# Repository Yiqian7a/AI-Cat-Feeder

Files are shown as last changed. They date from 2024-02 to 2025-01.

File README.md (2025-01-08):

## 设计思路

### 1.1 初代设计 v1.0

在最初的v1.0设计中，我给喂猫机设计了一个雪人外形，分离储粮仓和出粮装置，使用太阳能贴条[^1]和风力供电[^2]。

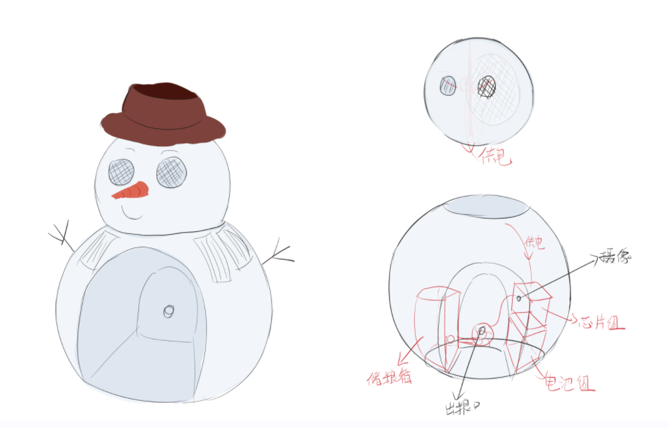
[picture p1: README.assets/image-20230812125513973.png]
图1.1
雪人身体的空腔部分（左图阴影）用来放置猫粮食盆，内部中空部分用来放置其他零部件，位置示意图如右图： 

（图1.1.1）

[^1]: （左图）雪人身体部分外侧的条状阴影。
[^2]: （右图）雪人头部内可以放入风力发电机和叶片，在雪人头部的后侧有一个大进风网口，前面的两个眼睛为出风网口。

出粮装置设计如下图，其分为两个部分：

- 蓝色的旋转件，工作时顺时针旋转，将猫粮从进粮口（右图左下的外壳缺口）带到最高点，再由重力作用将猫粮从出粮口（图1.1.1右图下部）导出。旋转件的内环有传动齿轮，这里由于前期模型丢失留到最后再介绍；
- 灰色的固定外壳，用以固定旋转件。

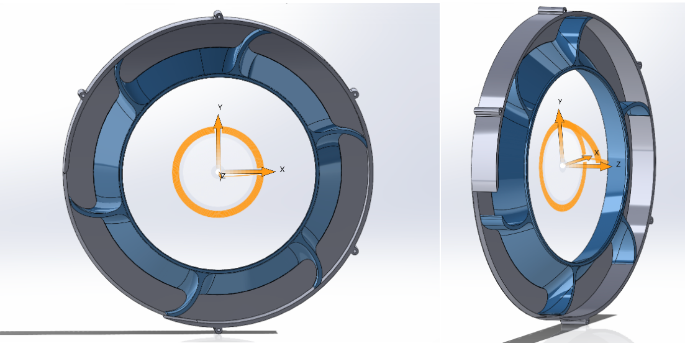
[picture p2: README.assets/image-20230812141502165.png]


（图1.1.2）

### 1.2 设计改良 v1.1

在完成设计v1.0 后的一段时间内，考虑到风力发电装置效率、组装接线、防水等问题，于是将雪人的头壳去除，改成了雪屋，并修改了3D设计：

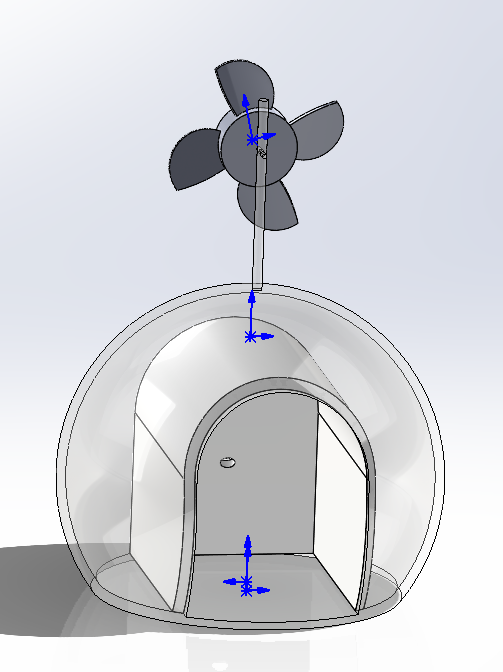
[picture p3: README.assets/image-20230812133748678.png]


（图1.2.1）

### 1.3 储粮优化 v1.2

考虑到v1.1储粮部分模型建模困难、连接组件过于复杂、更换粮食不方便等问题，我重新设计了一体式储粮送粮装置：

- 最上为进粮口，可以加上盖子；
- 主仓内有三个空腔（右图），最大的为储粮仓，左下为电机、电池仓，右下空仓没有使用；
- （左图）主仓右下角缺口凹槽为电池或用于主仓定位预留；
- （左图）控制主板和摄像头位于旋转件中间的空位（未画出），通过开孔与电池电机连接；

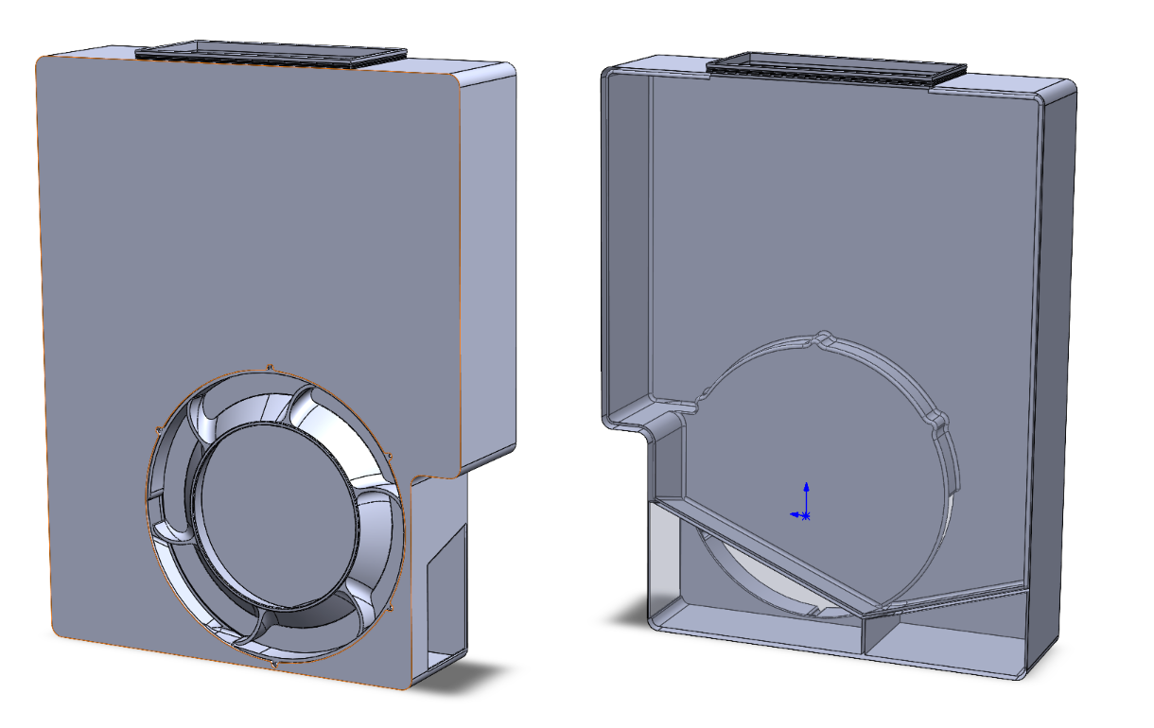
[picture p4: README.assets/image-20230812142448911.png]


（图1.3.1）

### 1.3 重制模型 v2.0

v1的设计提出不久就因为球状外壳装配繁琐、装置容错率低等问题而被否决了；同时测试v1.2版本的储粮仓由于坡度不够等问题无法顺利出粮。于是我开发了v2.0版本：

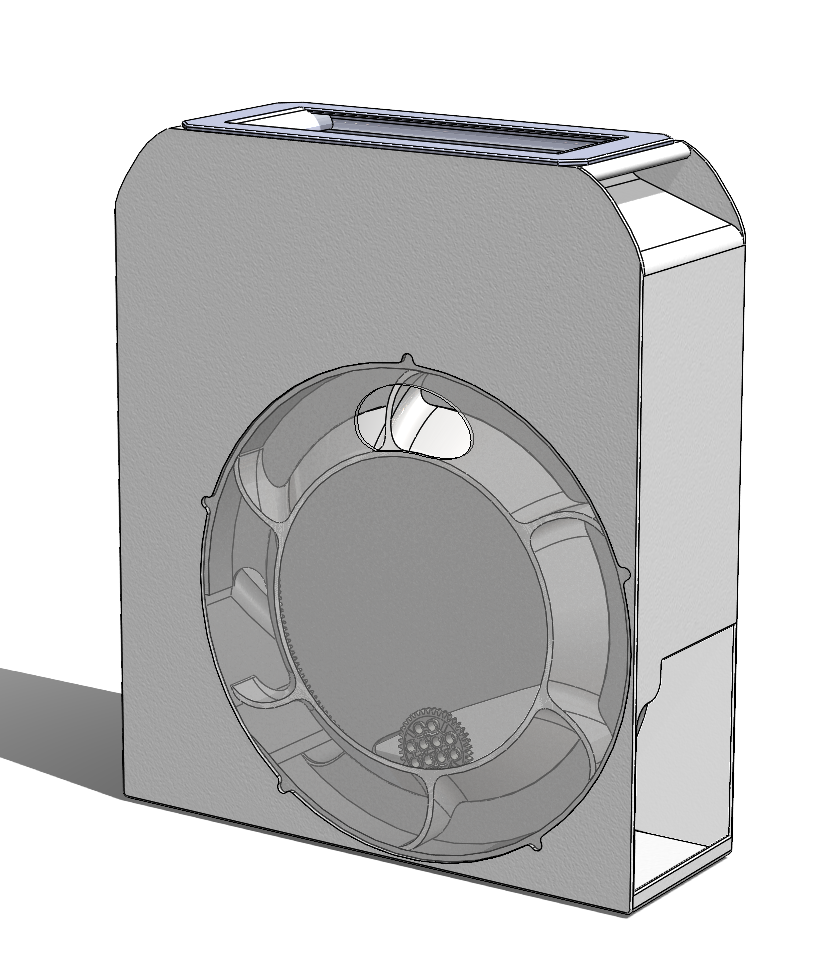
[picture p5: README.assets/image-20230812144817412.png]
（图1.3.1）

比起之前的v1.2（右），v2.0（左）版本对内部空间分配作了优化，同时增加了旋转环的尺寸和粮仓底部的倾角：

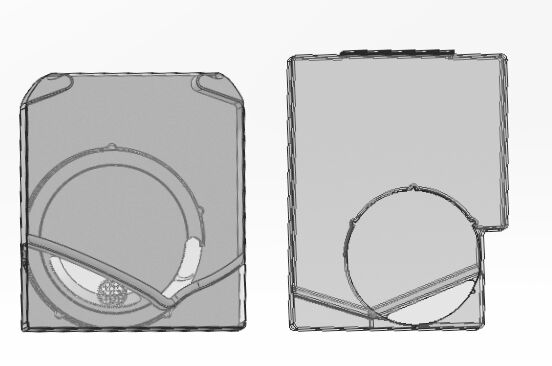
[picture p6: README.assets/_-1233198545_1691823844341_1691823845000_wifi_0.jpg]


（图1.3.2）

以下是详细讲解，左图为后视图，右图为爆炸视图：

- 最上方蓝色部分为储粮仓盖，用以防水防潮，其下方左右各有一片突出的薄片，用以卡住盖子，上方有打开盖子用的扣板；
- 在主仓上方的左右两侧有两个凹槽，是主仓的提手；

- 主仓内部分为上下两部分，上半部分用以储存猫粮，下半部分用于存放电池等各种装置；
- 最前面是一个透明挡板，同时用以展示和保护内部摄像头、主板等装置；
- 左图下部可以看到齿轮的传动连接，电机驱动该齿轮以带动出粮。

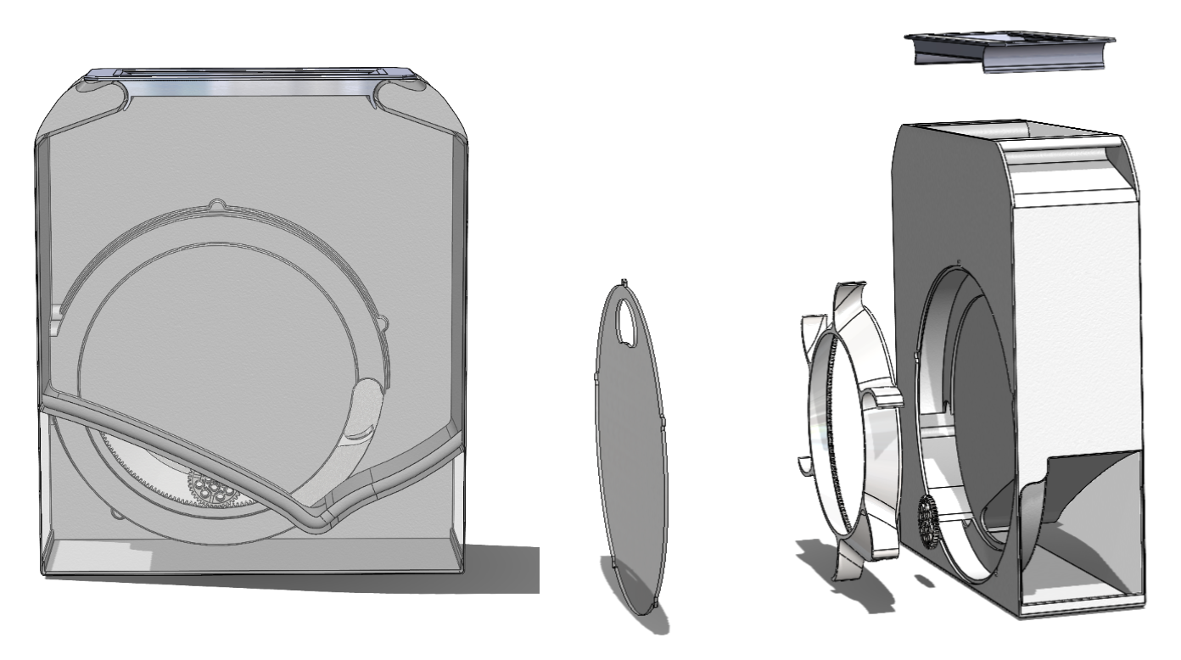
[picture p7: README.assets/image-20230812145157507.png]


（图1.3.2）

### 1.4 外壳整体 v2.1

整体外形设计为古罗马神殿风格，采用底座、外壳、屋顶三层拼装，方便拆装。主视图如下：

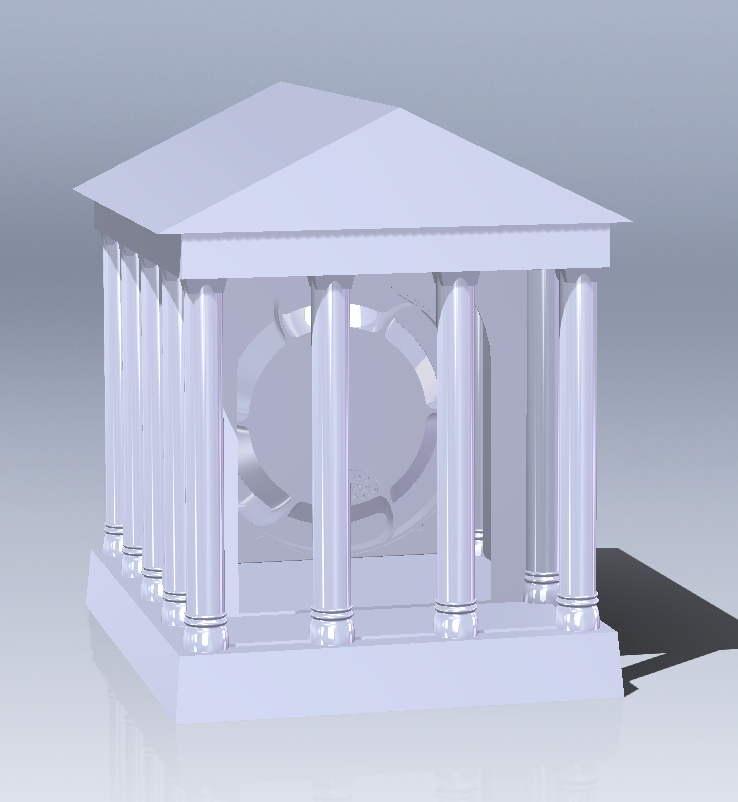
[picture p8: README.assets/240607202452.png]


顶部透视图：

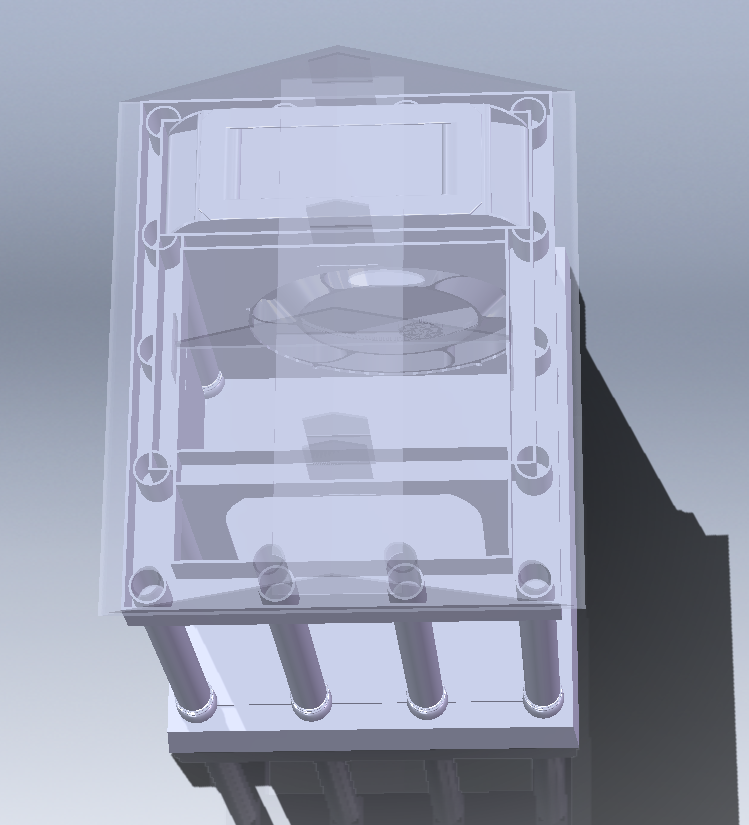
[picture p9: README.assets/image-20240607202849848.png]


### 1.5 最终版 v2.2

最终版修改了正门前的两个柱子，防止猫咪卡住或进不去，同时增大了喂猫机的内部空间。

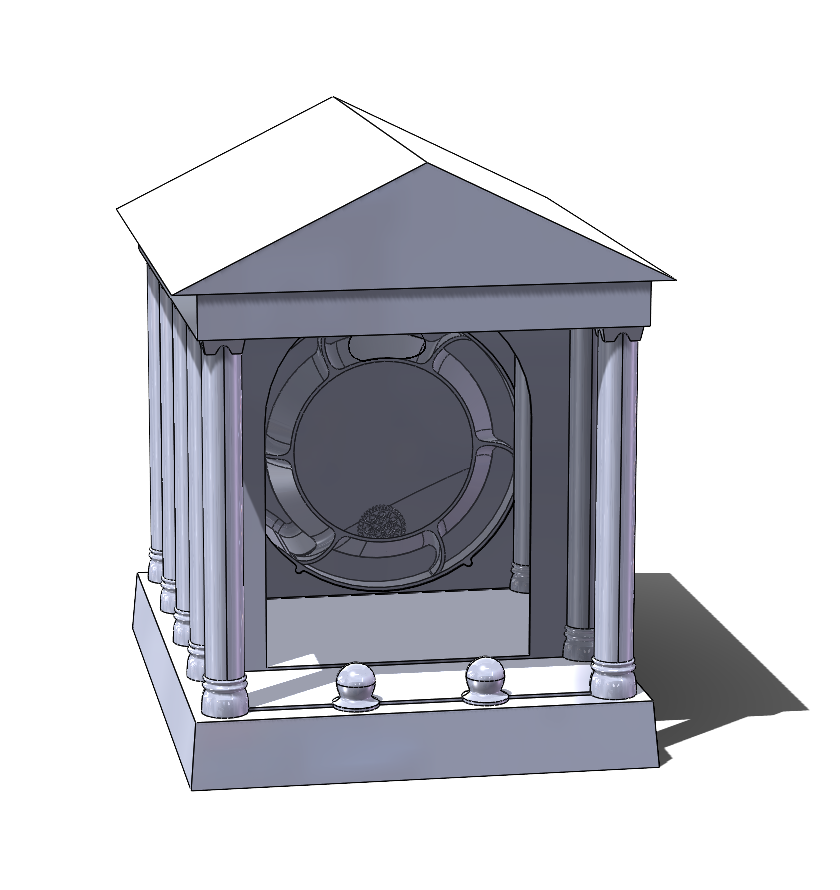
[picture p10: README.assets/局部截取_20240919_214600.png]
局部截取_20240919_214600


## 成品展示

最终结果请参照下面实物图：

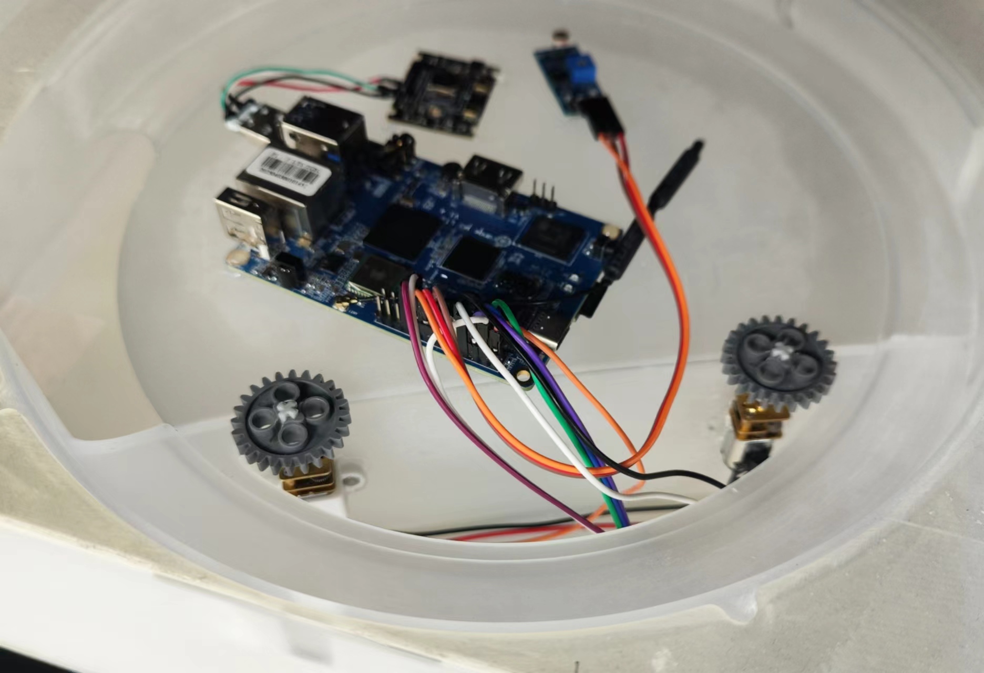
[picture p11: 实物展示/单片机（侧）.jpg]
单片机（侧）


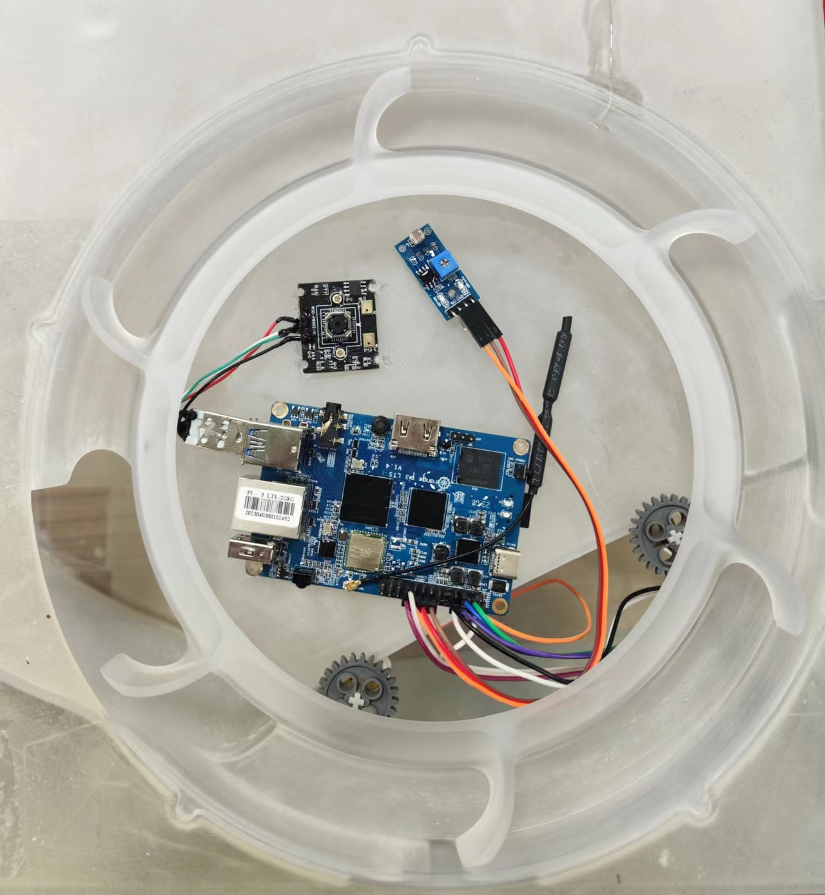
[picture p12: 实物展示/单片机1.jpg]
单片机1


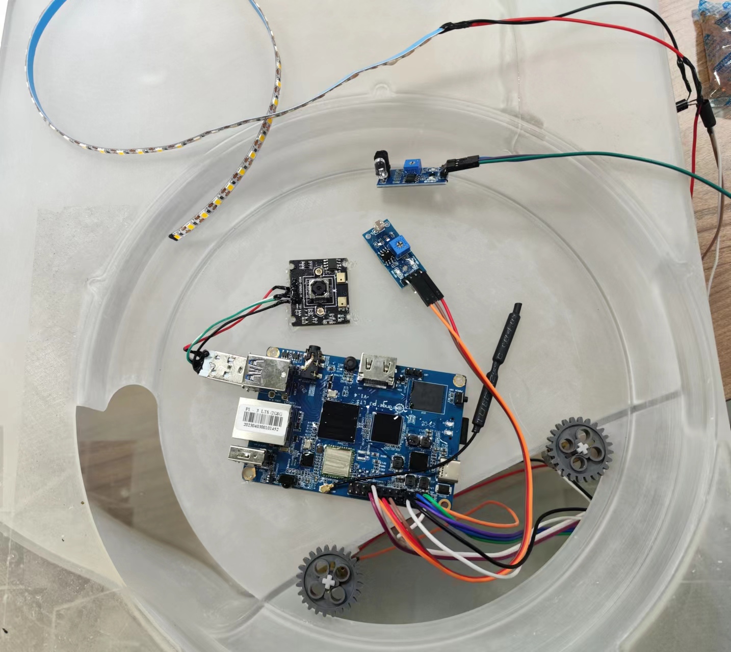
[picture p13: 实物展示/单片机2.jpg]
单片机2


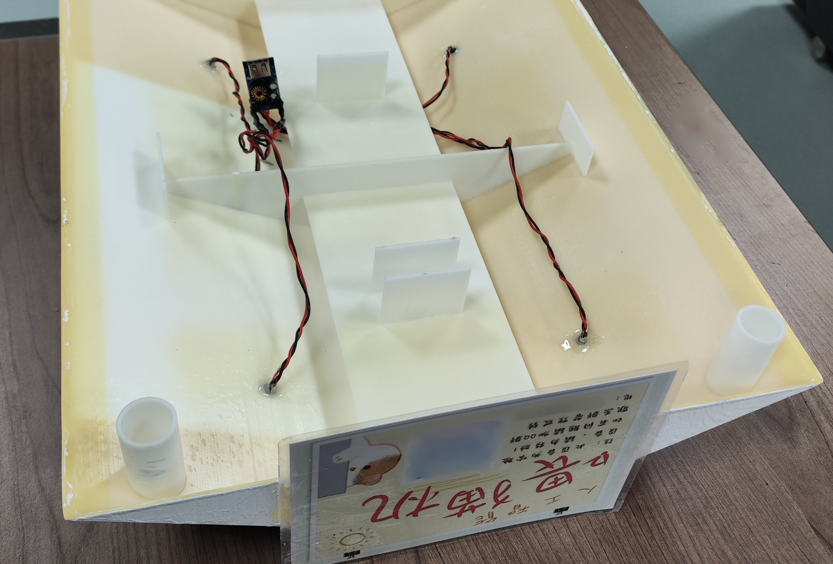
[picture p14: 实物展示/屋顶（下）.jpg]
屋顶（下）


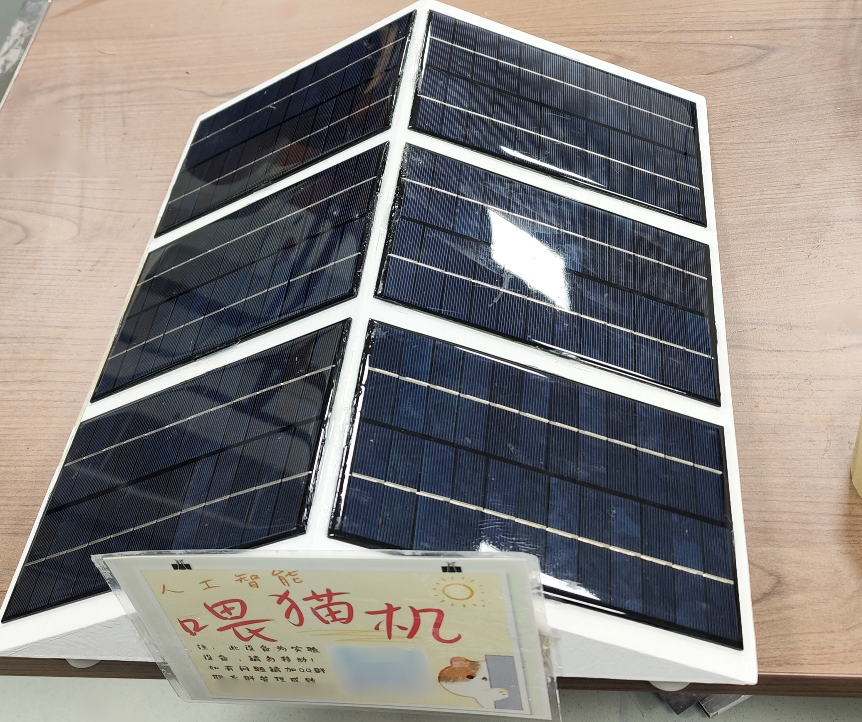
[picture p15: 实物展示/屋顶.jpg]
屋顶


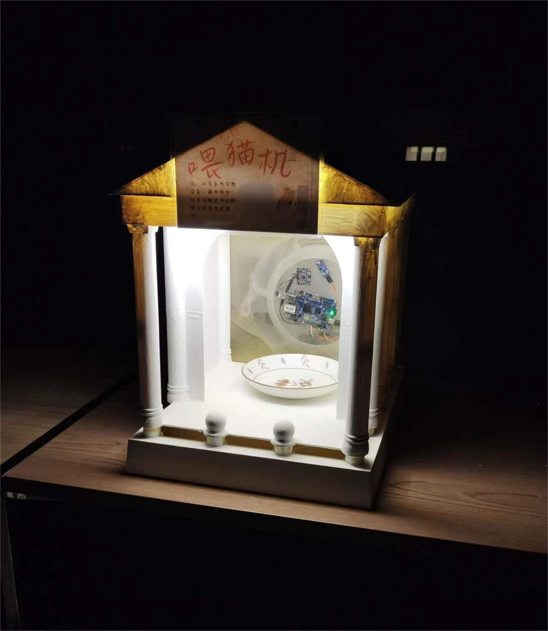
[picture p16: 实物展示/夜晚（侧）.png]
夜晚（侧）


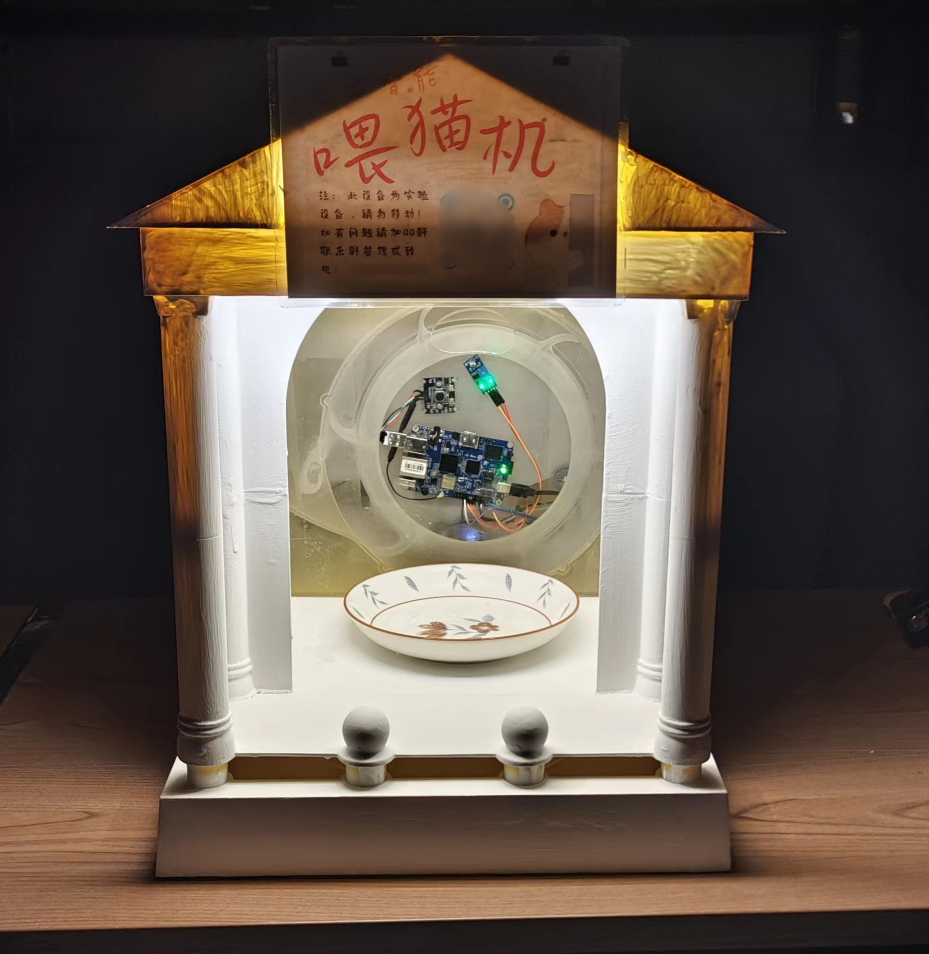
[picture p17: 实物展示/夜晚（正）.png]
夜晚（正）


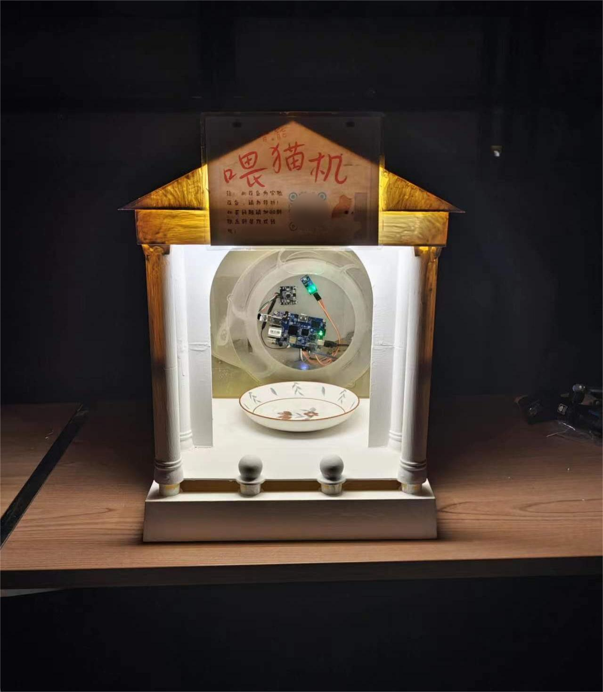
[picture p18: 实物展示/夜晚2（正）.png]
夜晚2（正）


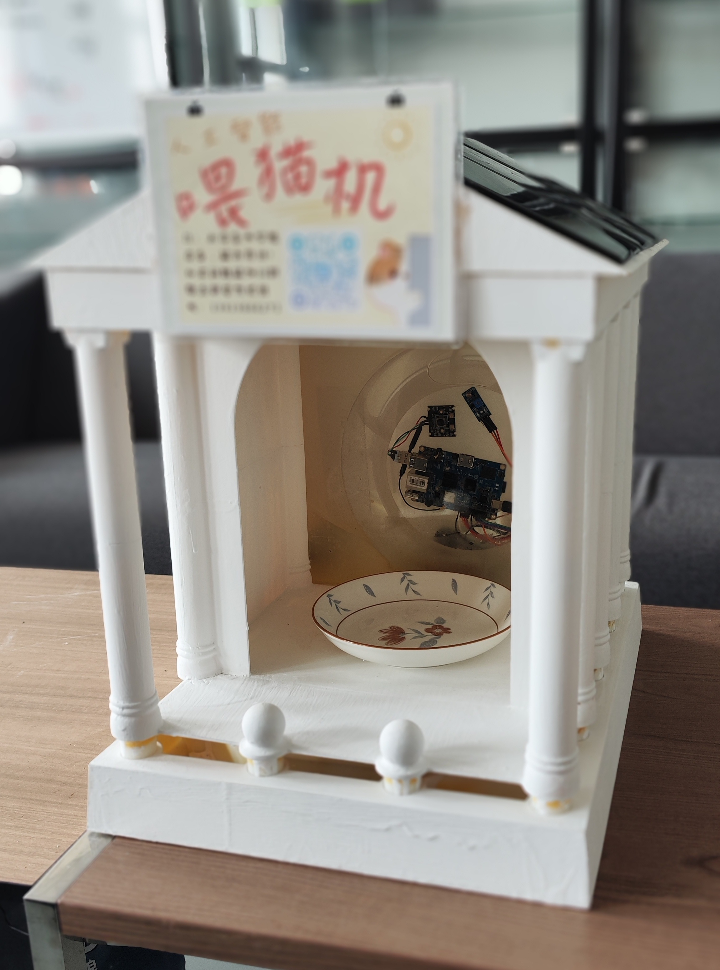
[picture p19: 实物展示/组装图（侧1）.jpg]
组装图（侧1）


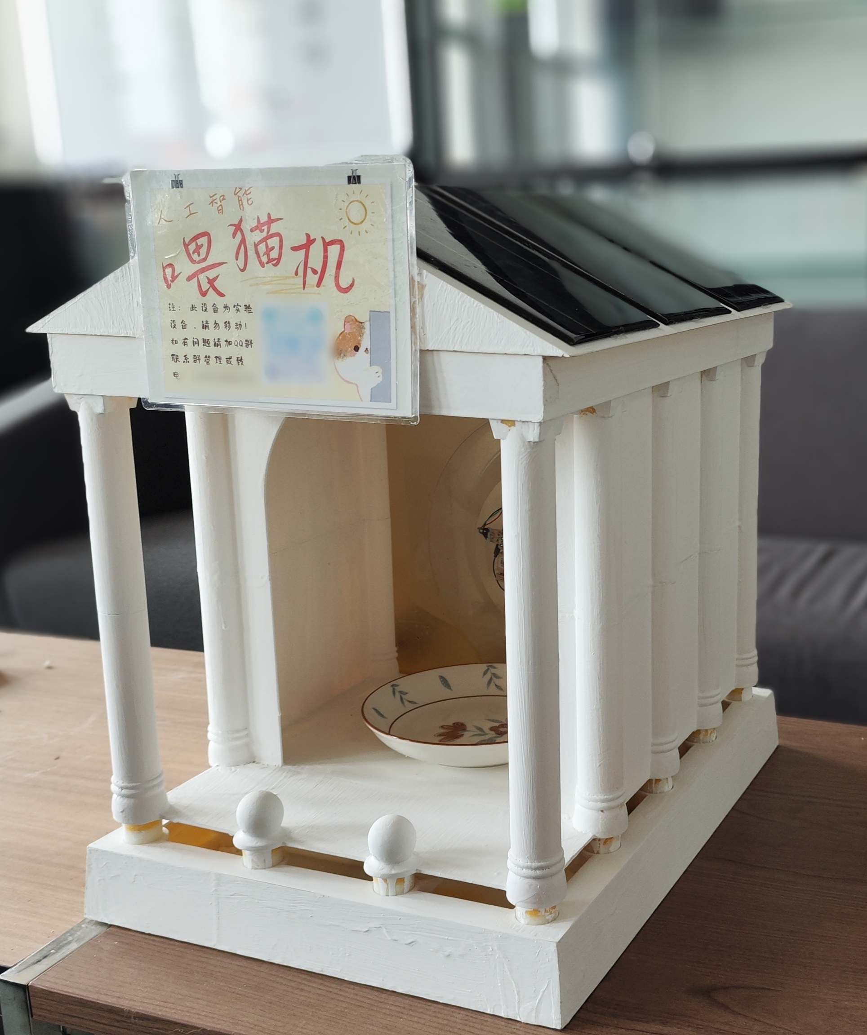
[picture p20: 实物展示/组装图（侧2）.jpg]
组装图（侧2）


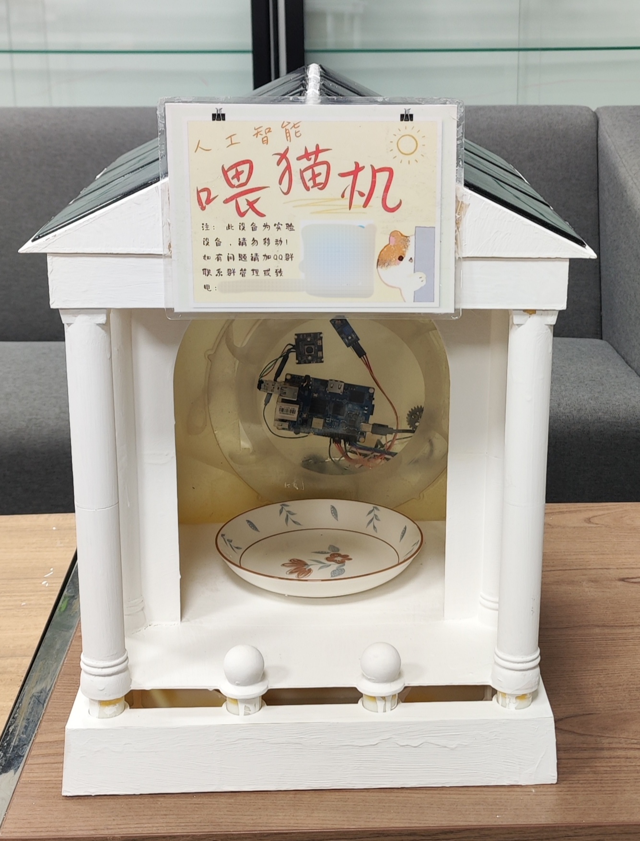
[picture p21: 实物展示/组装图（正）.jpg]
组装图（正）


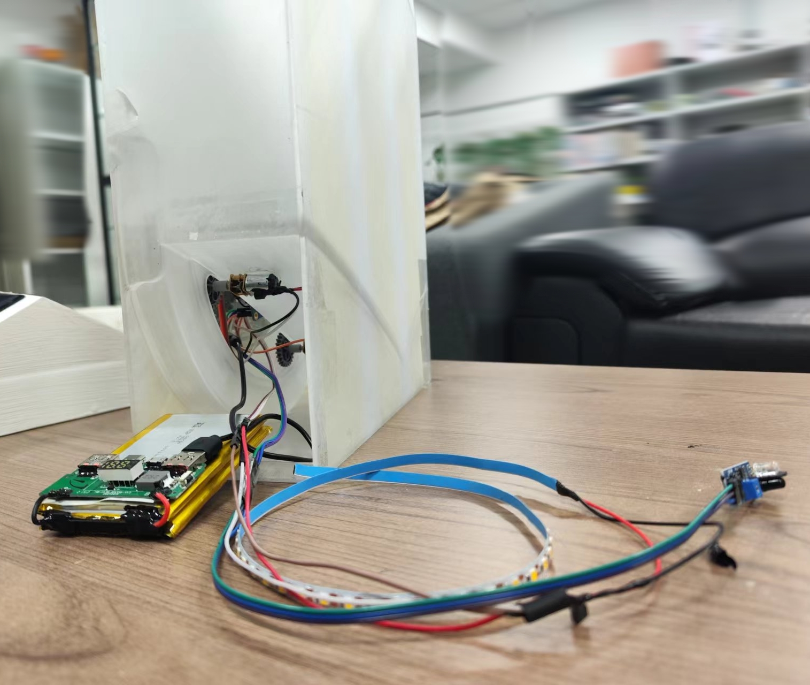
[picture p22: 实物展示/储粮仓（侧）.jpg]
储粮仓（侧）


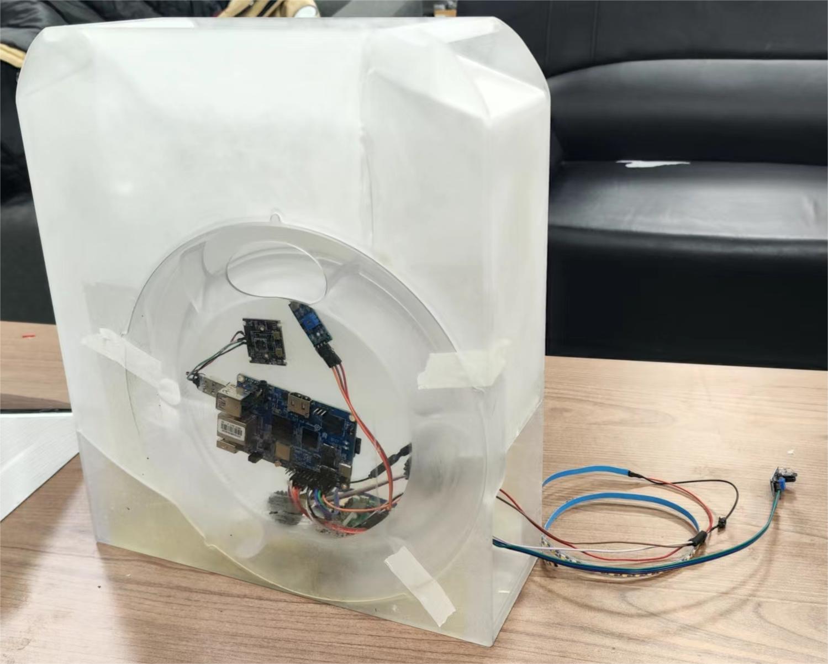
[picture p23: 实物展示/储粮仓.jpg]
储粮仓


实际使用中，转轮的设计还是容易出现卡粮的情况，因此这是一个十分大胆的设计。

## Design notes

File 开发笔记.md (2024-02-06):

## 2. 配置环境

### 2.1 安装miniconda

### 2.2 修改gpio映射

进入OPi库的路径修改

```bash
cd /usr/local/lib/
find . -name "OPi*"
```

进入OPi文件夹下，找到`pin_mappings.py`文件

将下面的映射字典替换原有的字典，注意只要修改`BOARD{ }`中的内容：

```python
_pin_map = {
    BOARD: {
        3: 122,
        5: 121,
        7: 118,
        8: 354,
        10: 355,
        11: 120,
        12: 114,
        13: 119,
        15: 362,
        16: 111,
        18: 112,
        19: 229,
        21: 230,
        22: 117,
        23: 228,
        24: 227,
        26: 360
    },
```

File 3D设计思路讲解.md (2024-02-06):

## 3D设计思路讲解

### 1. 设计思路

#### 1.1 初代设计 v1.0

在最初的v1.0设计中，我给喂猫机设计了一个雪人外形，分离储粮仓和出粮装置，使用太阳能贴条[^1]和风力供电[^2]。

雪人身体的空腔部分（左图阴影）用来放置猫粮食盆，内部中空部分用来放置其他零部件，位置示意图如右图：图1.1 

（图1.1.1）

[^1]: （左图）雪人身体部分外侧的条状阴影。
[^2]: （右图）雪人头部内可以放入风力发电机和叶片，在雪人头部的后侧有一个大进风网口，前面的两个眼睛为出风网口。

出粮装置设计如下图，其分为两个部分：

- 蓝色的旋转件，工作时顺时针旋转，将猫粮从进粮口（右图左下的外壳缺口）带到最高点，再由重力作用将猫粮从出粮口（图1.1.1右图下部）导出。旋转件的内环有传动齿轮，这里由于前期模型丢失留到最后再介绍；
- 灰色的固定外壳，用以固定旋转件。



（图1.1.2）

#### 1.2 设计改良 v1.1

在完成设计v1.0 后的一段时间内，考虑到风力发电装置效率、组装接线、防水等问题，于是将雪人的头壳去除，改成了雪屋，并修改了3D设计：



（图1.2.1）

#### 1.3 储粮优化 v1.2

考虑到v1.1储粮部分模型建模困难、连接组件过于复杂、更换粮食不方便等问题，我重新设计了一体式储粮送粮装置：

- 最上为进粮口，可以加上盖子；
- 主仓内有三个空腔（右图），最大的为储粮仓，左下为电机、电池仓，右下空仓没有使用；
- （左图）主仓右下角缺口凹槽为电池或用于主仓定位预留；
- （左图）控制主板和摄像头位于旋转件中间的空位（未画出），通过开孔与电池电机连接；



（图1.3.1）

#### 1.3 重制模型 v2.0

v1的设计提出不久就因为球状外壳装配繁琐、装置容错率低等问题而被否决了；同时测试v1.2版本的储粮仓由于坡度不够等问题无法顺利出粮。于是我开发了v2.0版本：

（图1.3.1）

比起之前的v1.2（右），v2.0（左）版本对内部空间分配作了优化，同时增加了旋转环的尺寸和粮仓底部的倾角：



（图1.3.2）

以下是详细讲解，左图为后视图，右图为爆炸视图：

- 最上方蓝色部分为储粮仓盖，用以防水防潮，其下方左右各有一片突出的薄片，用以卡住盖子，上方有打开盖子用的扣板；
- 在主仓上方的左右两侧有两个凹槽，是主仓的提手；

- 主仓内部分为上下两部分，上半部分用以储存猫粮，下半部分用于存放电池等各种装置；
- 最前面是一个透明挡板，同时用以展示和保护内部摄像头、主板等装置；
- 左图下部可以看到齿轮的传动连接，电机驱动该齿轮以带动出粮。



（图1.3.2）

#### 1.4 外壳整体 v2.1

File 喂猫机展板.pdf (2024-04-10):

# 人 工 智 能 自 动 喂 猫 机

刘宇昊、陈峻松、梁羽枫、王浚弛、陈智鹏、王震豪、陈梓博 ——2022级数据科学与人工智能实验班

人工智能自动喂猫机项目是22级
数科班大一学年的大作业，目标是为流
浪猫设计一个户外喂猫机，能够自主全
天候自动识别猫并投放猫粮。 项目简介 | 相关技术 | 成果展示

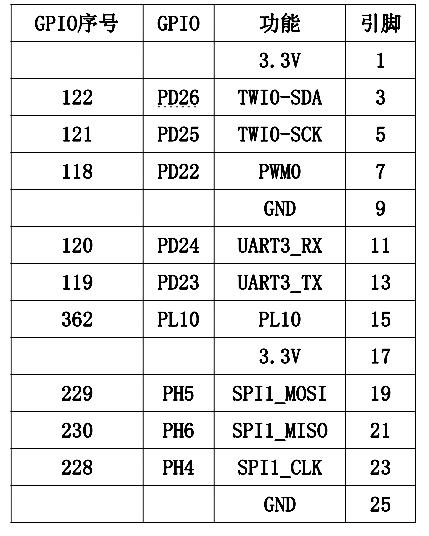
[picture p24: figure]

原理解析

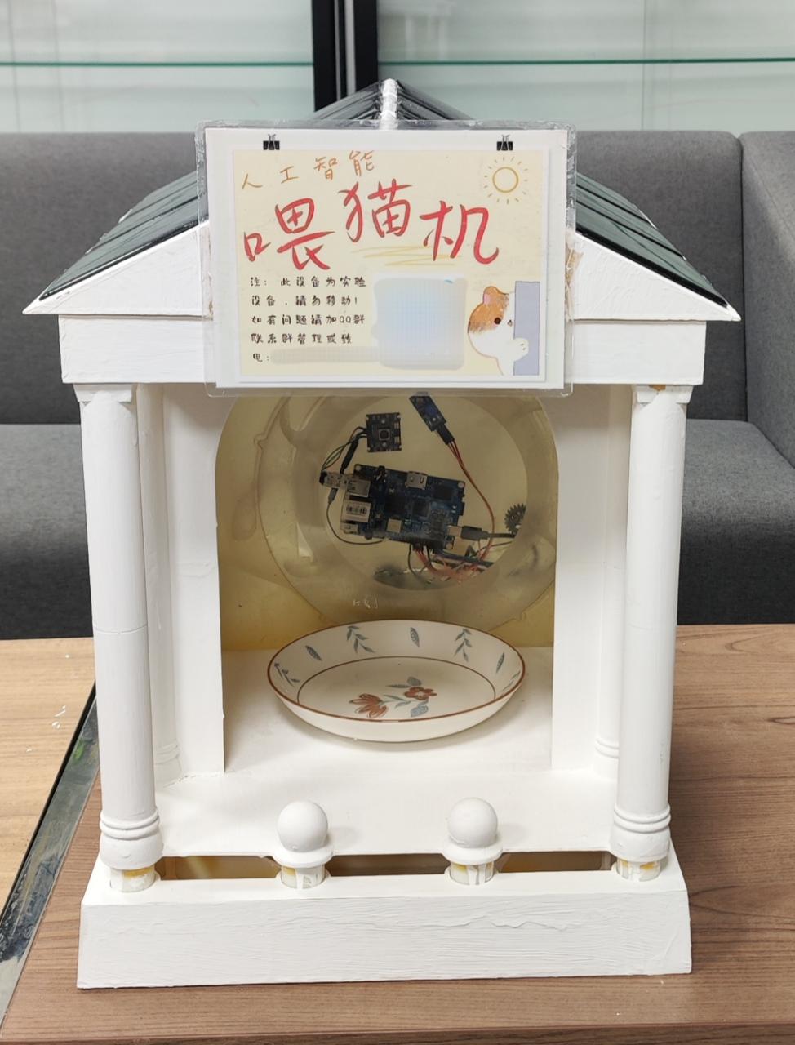
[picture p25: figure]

## OrangePi-3-LTS Ubuntu 22.04

本项目的主控板使用
OrangePi-3-LTS。作为低
成本高性能的嵌入式开发
板，比起ESP32等单片机
具有更强大的计算性能和
兼容性，可以支持神经网
络推理任务。

ncnn框架是由腾讯研发的专注于移动设备和嵌入式系统上的高效神经网络前向 计算框架，利用硬件加速功能实现低资源消耗的计算任务。ncnn 从设计之初深刻考

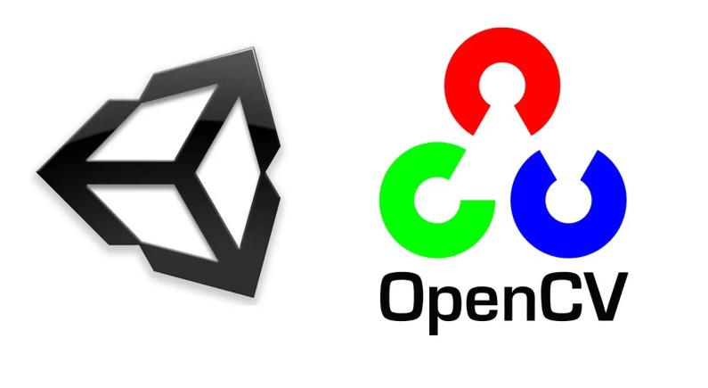
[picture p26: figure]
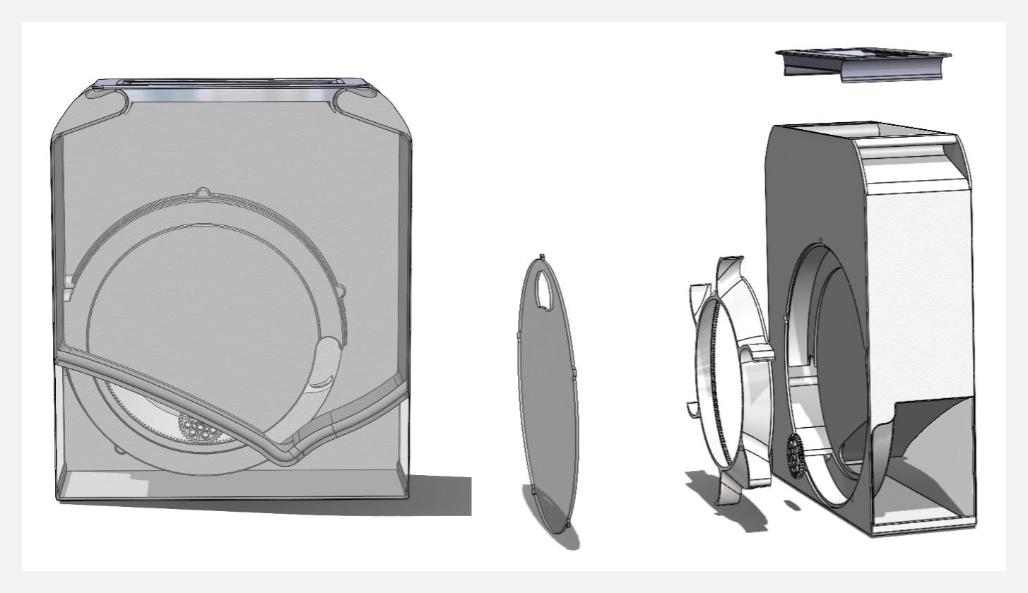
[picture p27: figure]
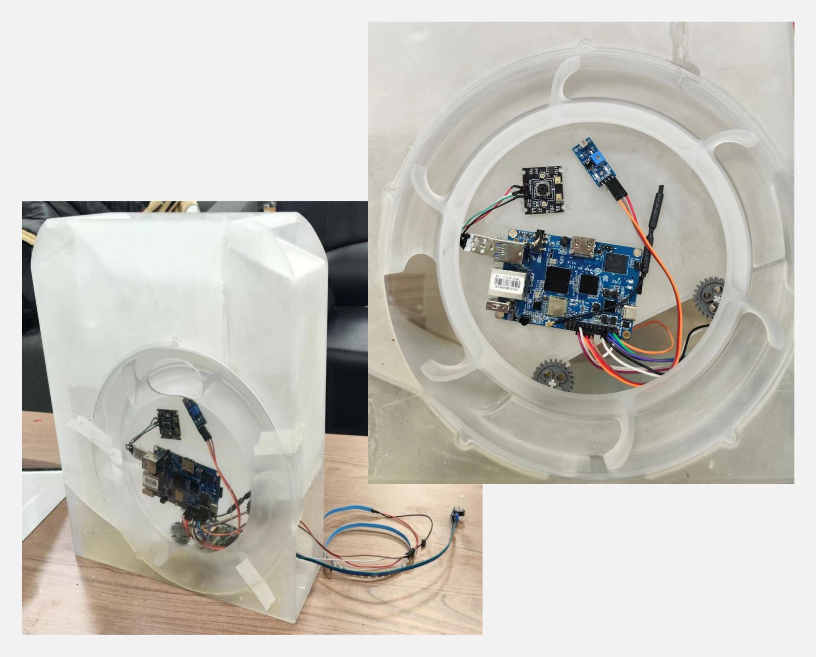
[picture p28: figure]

虑移动端的部署和使用， 无第三方依赖，移动端 cpu 的速度快于目前所有已知的开 源框架。

喂 猫 机 在 白
天和夜间具有两
种 不 同 工 作 状
态，但识别猫的
逻辑基本相同。

NanoDet 是一种 FCOS 式的单阶段 anchor-free 目标检测模型，它使用 ATSS 进行目标采样， 使用 Generalized Focal Loss 损失函数（GLF）执 行分类和边框回归。

项目团队完成了自主调研学校
内流浪猫生存情况，根据需求设计
出了喂猫机基本思路；自行设计
3D模型并打印、打磨、拼装成
型；自行设计硬件电路；自主选择
控制主机，搭建控制系统，自主撰
写控制逻辑等工作，从零开始，历
经一年，完整地开发出了人工智能
喂猫机产品，并成功投入使用。

为展示该项目，项目团队为每个阶段专门制作了讲
解视频并发布在BiliBili网站。项目的代码完全公开，其

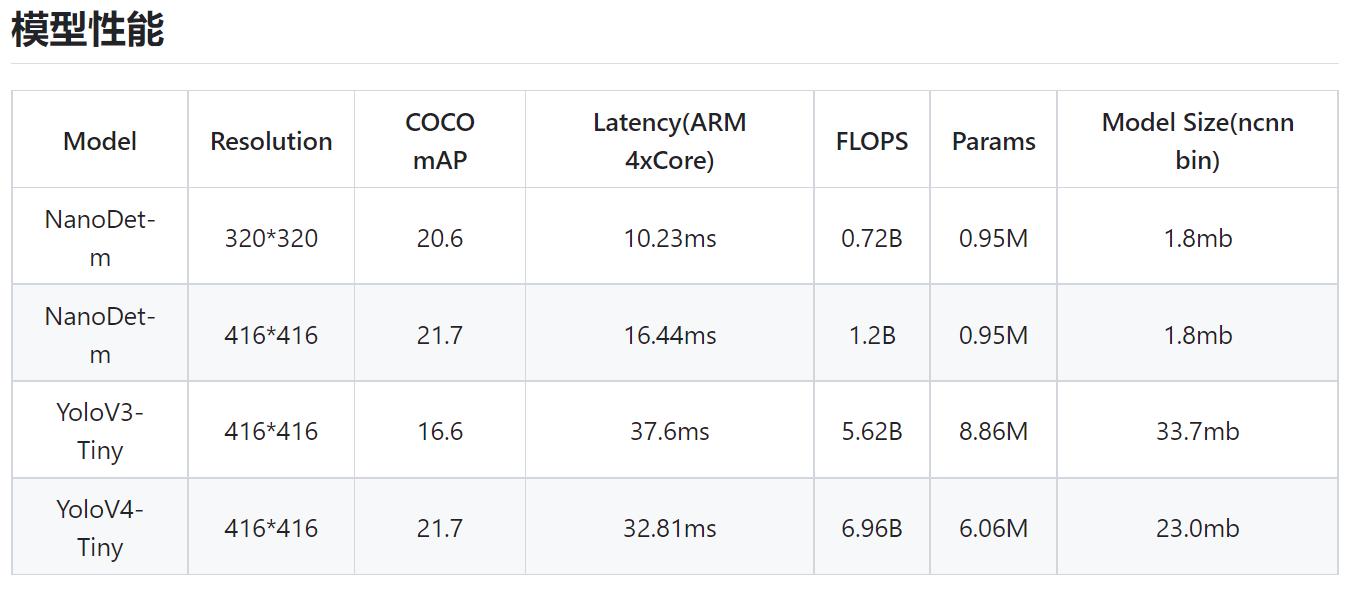
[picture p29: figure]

中也包含了项目的完整复现教程。

## Nanodet

## ncnn

喂猫机上装有光学传感器，根据光照强度决
定是否打开自带灯光。同时光学传感器作为第一
层检查机制，只有当受到阻挡时才会开启摄像头
监测，以减少电量消耗；

为了精确控制食碗中的余粮，喂猫机上配备
了红外传感器，利用猫粮和食碗反射红外光线程
度不同来判断猫粮余量，检测到余粮不足才会投
放猫粮。

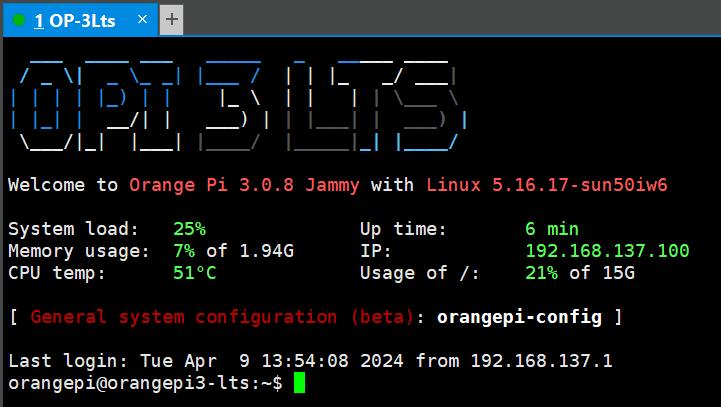
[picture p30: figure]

当摄像头开启时
会调用喂猫机上搭载
的猫咪识别算法，并
保留每次识别结果的
可视化照片。
白天工作 | 夜间工作

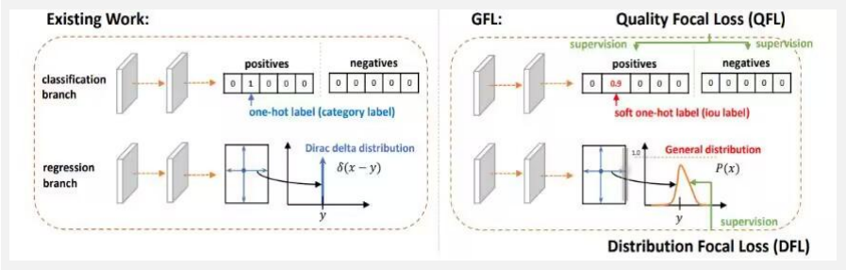
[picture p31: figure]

比起YOLO、SSD、Fast R-CNN等模型在目标 检测方面速度略慢、精度略低但模型比较小。本项目
基于ncnn框架将其移植到了OrangePi-3-lts开发板 上。

## OpenCV

项目团队在开发板上
配置了Ubuntu22.04系
统，使用Xshell进行远程
开发和程序部署。并给配
置了守护进程，以便意外
重启也能自动恢复运行。

## OPi.GPIO

OPi.GPIO是一个使用
Python 控制 Orangpi 这类开
发板GPIO引脚的软件包。

OpenCV 是基于计算机
视觉的图像处理开源库

硬件系统

喂猫机的部分3D爆炸图和内部结构（完整设计在
Gitee仓库）

B站视频

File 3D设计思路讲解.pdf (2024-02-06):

# 3D设计思路讲解

## 1. 设计思路

## 1.1 初代设计 v1.0

在最初的v1.0设计中，我给喂猫机设计了一个雪人外形，分离储粮仓和出粮装置，使用太阳能贴条 1 和风力供电 ² 。

雪人身体的空腔部分（左图阴影）用来放置猫粮食盆，内部中空部分用来放置其他零部件，位置示 意图如右图：


（图1.1.1）

出粮装置设计如下图，其分为两个部分：

蓝色的旋转件，工作时顺时针旋转，将猫粮从进粮口（右图左下的外壳缺口）带到最高点，再 由重力作用将猫粮从出粮口（图1.1.1右图下部）导出。旋转件的内环有传动齿轮，这里由于前 期模型丢失留到最后再介绍；
灰色的固定外壳，用以固定旋转件。

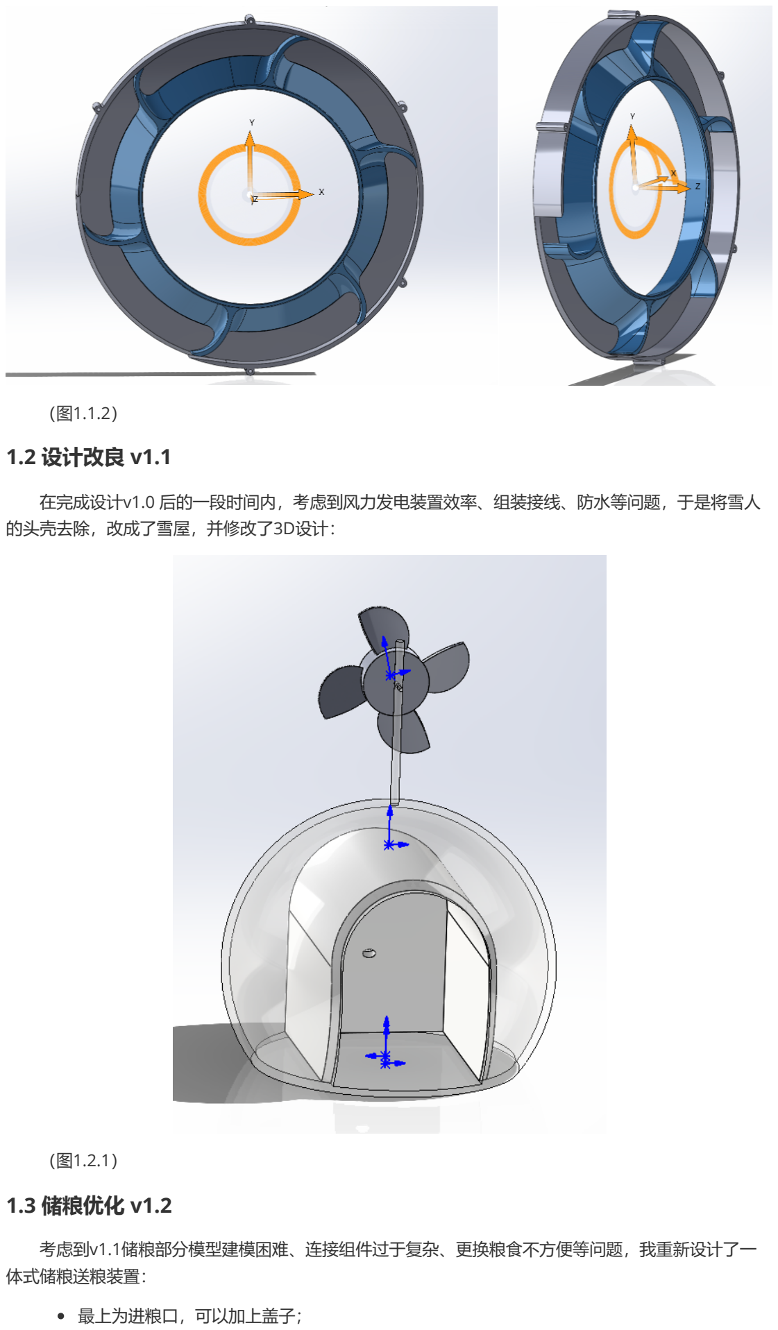
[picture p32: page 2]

（图1.1.2）

## 1.2 设计改良 v1.1

在完成设计v1.0 后的一段时间内，考虑到风力发电装置效率、组装接线、防水等问题，于是将雪人 的头壳去除，改成了雪屋，并修改了3D设计：

（图1.2.1）

## 1.3 储粮优化 v1.2

考虑到v1.1储粮部分模型建模困难、连接组件过于复杂、更换粮食不方便等问题，我重新设计了一 体式储粮送粮装置：

最上为进粮口，可以加上盖子；

主仓内有三个空腔（右图），最大的为储粮仓，左下为电机、电池仓，右下空仓没有使用； （左图）主仓右下角缺口凹槽为电池或用于主仓定位预留； （左图）控制主板和摄像头位于旋转件中间的空位（未画出），通过开孔与电池电机连接；


（图1.3.1）

## 1.3 重制模型 v2.0

v1的设计提出不久就因为球状外壳装配繁琐、装置容错率低等问题而被否决了；同时测试v1.2版本 的储粮仓由于坡度不够等问题无法顺利出粮。于是我开发了v2.0版本：


（图1.3.1）

比起之前的v1.2（右），v2.0（左）版本对内部空间分配作了优化，同时增加了旋转环的尺寸和粮仓 底部的倾角：

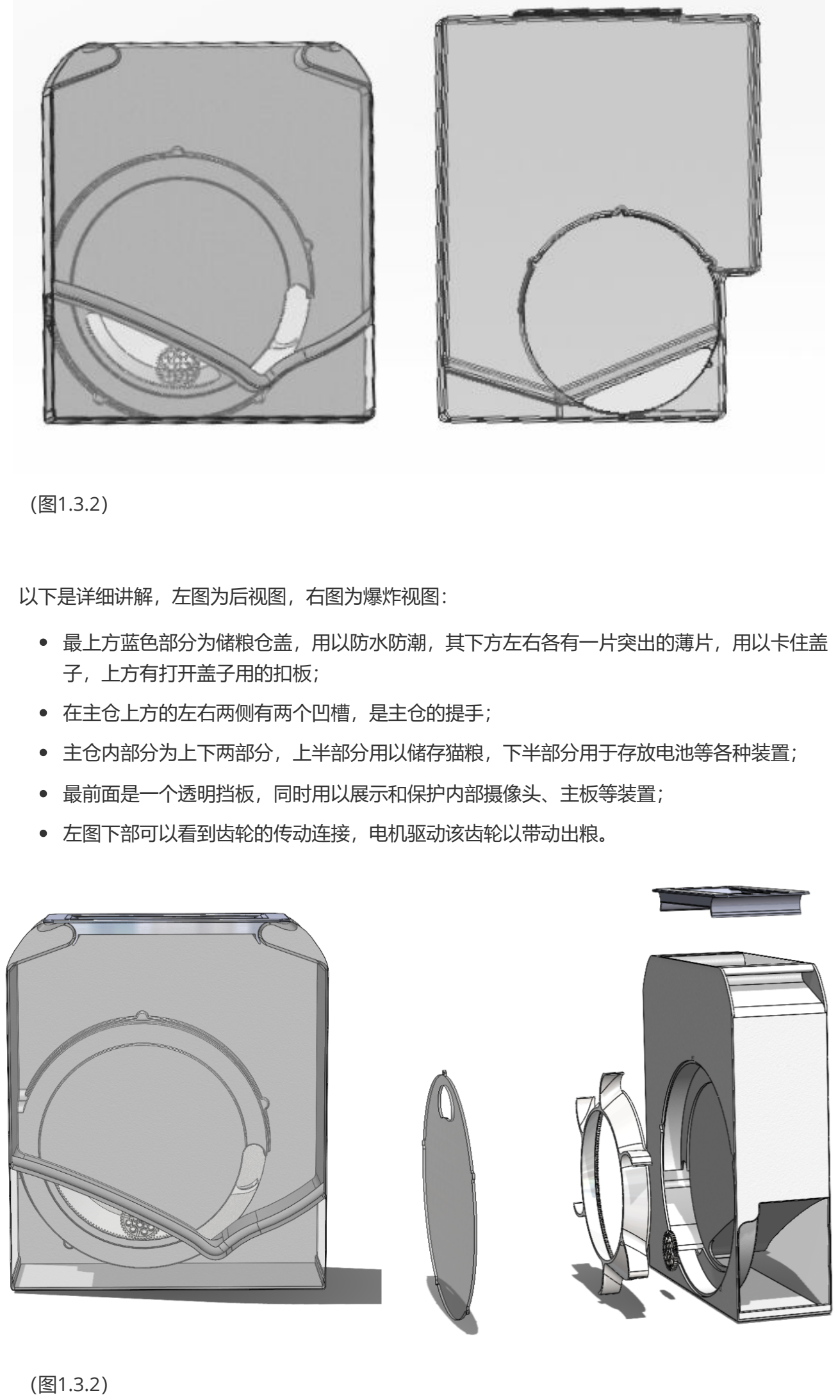
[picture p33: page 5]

（图1.3.2）

以下是详细讲解，左图为后视图，右图为爆炸视图：

最上方蓝色部分为储粮仓盖，用以防水防潮，其下方左右各有一片突出的薄片，用以卡住盖 子，上方有打开盖子用的扣板；
在主仓上方的左右两侧有两个凹槽，是主仓的提手；
主仓内部分为上下两部分，上半部分用以储存猫粮，下半部分用于存放电池等各种装置； 最前面是一个透明挡板，同时用以展示和保护内部摄像头、主板等装置； 左图下部可以看到齿轮的传动连接，电机驱动该齿轮以带动出粮。

（图1.3.2）

1. （左图）雪人身体部分外侧的条状阴影。 ↩
2. （右图）雪人头部内可以放入风力发电机和叶片，在雪人头部的后侧有一个大进风网口，前面的两个眼睛为出风网口。 ↩

## 1.4 外壳整体 v2.1

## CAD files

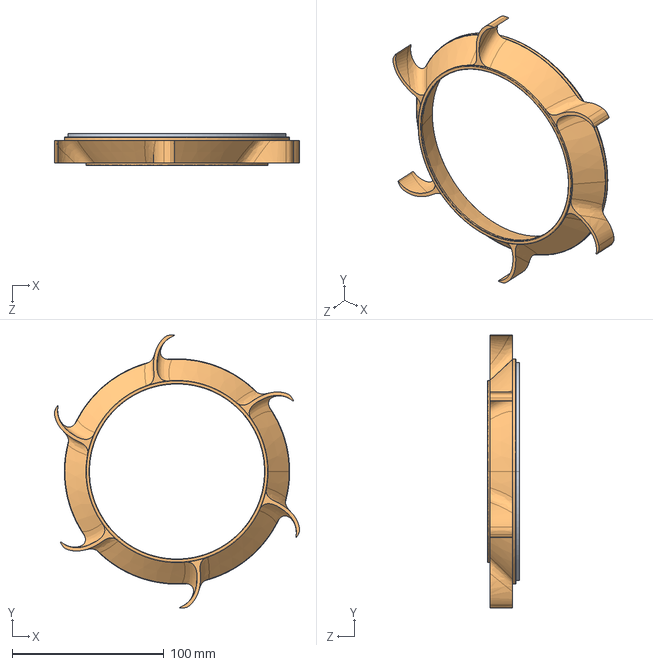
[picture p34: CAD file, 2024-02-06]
3D模型/1.1/旋转件.STEP
161.6 x 179.9 x 21.1 mm

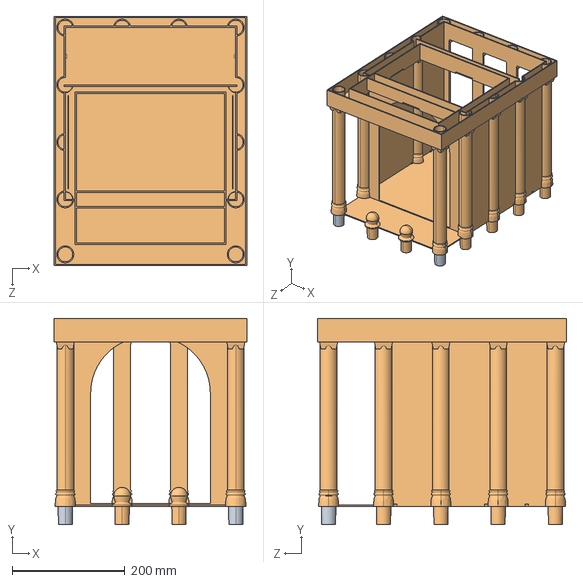
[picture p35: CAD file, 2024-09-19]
3D模型/2.0/外壳.STEP
342.1 x 365.5 x 442.0 mm

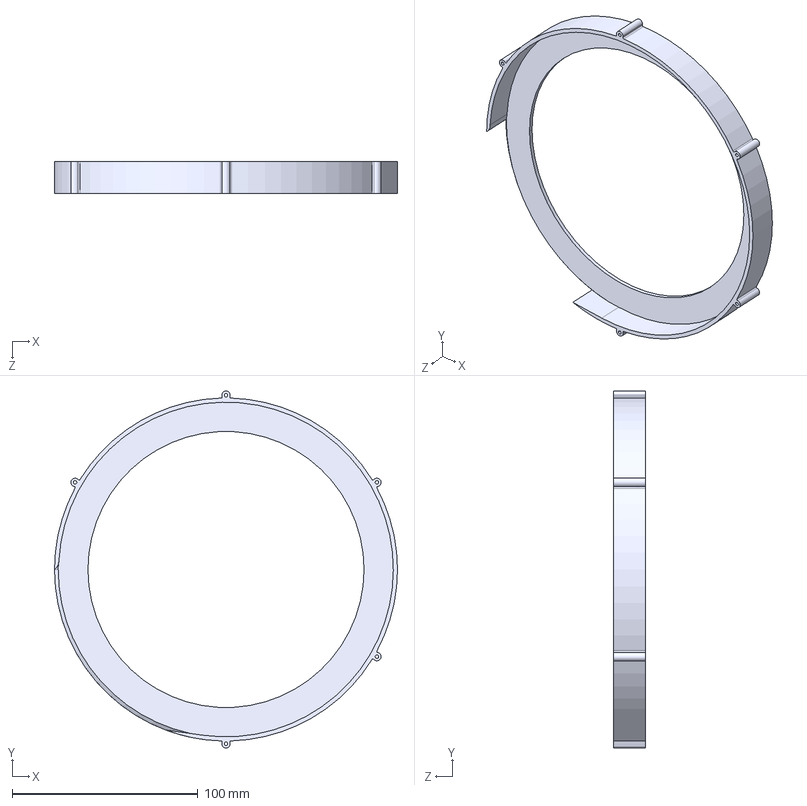
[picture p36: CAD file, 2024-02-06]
3D模型/1.1/旋转体外壳.STEP
184.5 x 192.0 x 17.3 mm

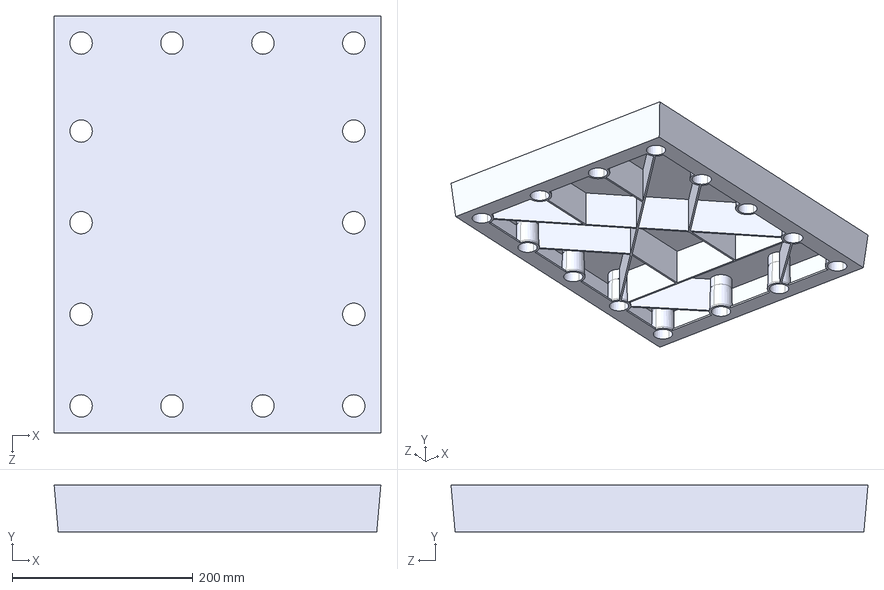
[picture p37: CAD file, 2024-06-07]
3D模型/2.0/底座.STEP
362.0 x 52.0 x 462.0 mm

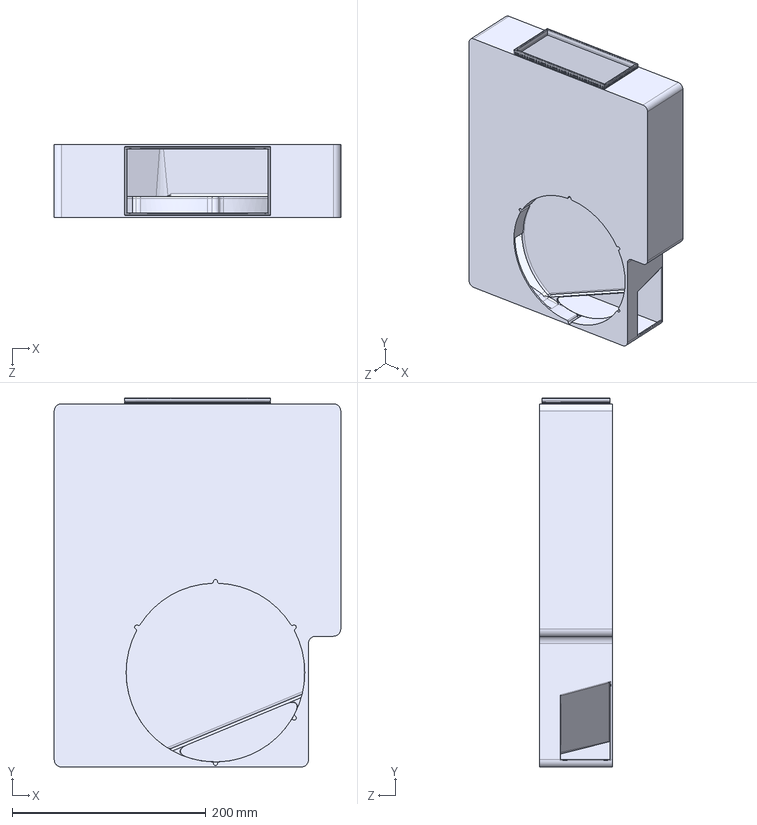
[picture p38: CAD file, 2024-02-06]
3D模型/1.1/储粮.STEP
295.9 x 381.0 x 75.0 mm

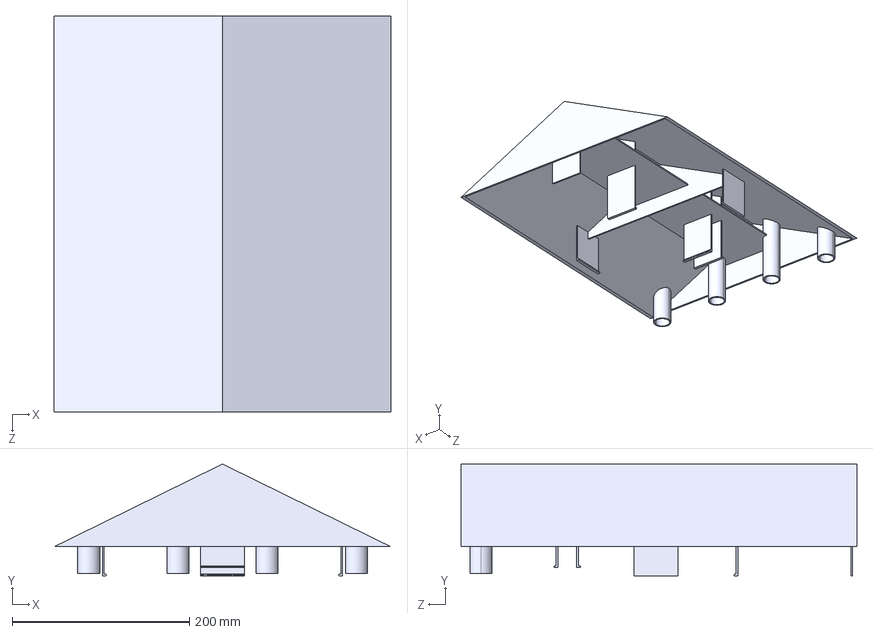
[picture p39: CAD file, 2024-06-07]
3D模型/2.0/屋顶.STEP
380.0 x 126.3 x 447.0 mm

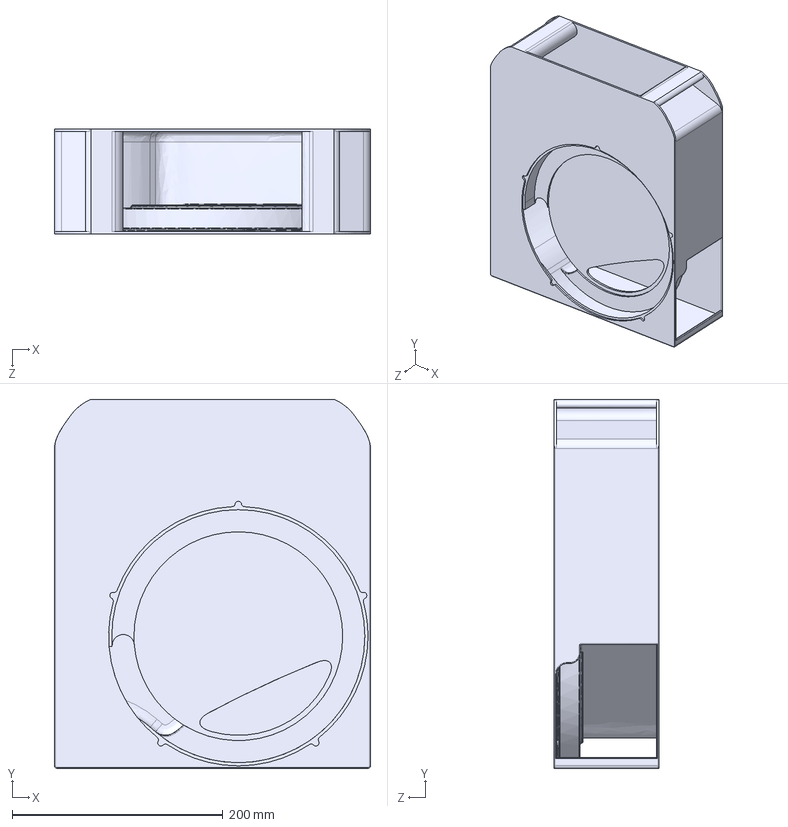
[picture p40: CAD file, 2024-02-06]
3D模型/2.0/主仓.STEP
300.0 x 350.0 x 100.0 mm

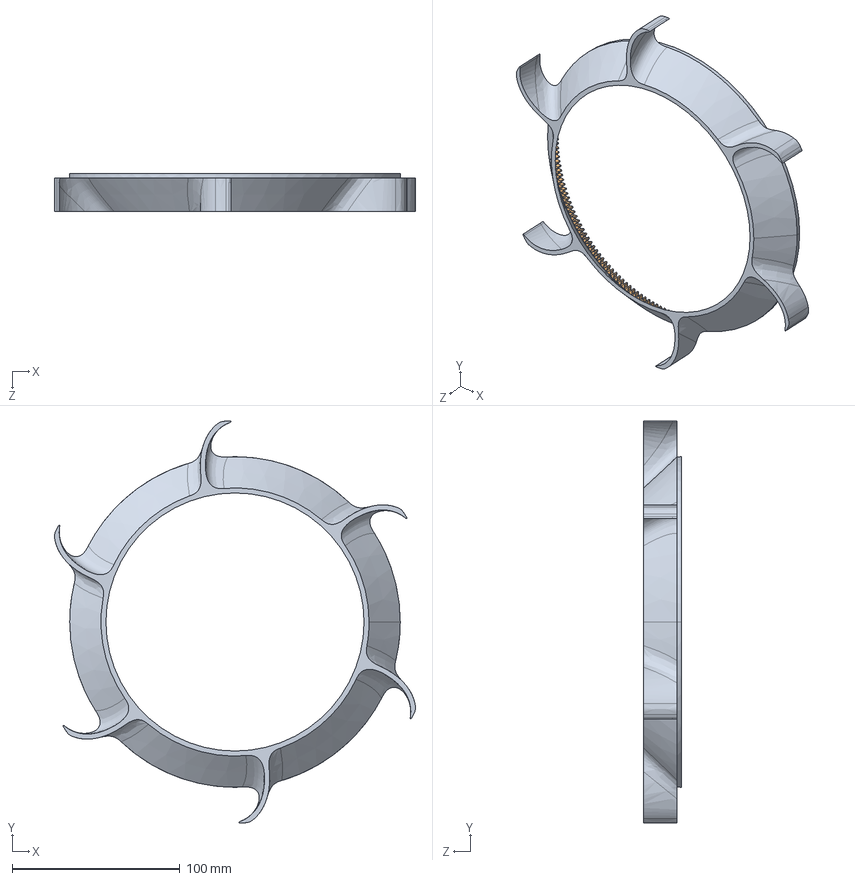
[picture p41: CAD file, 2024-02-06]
3D模型/2.0/旋转件.STEP
215.5 x 239.9 x 22.5 mm

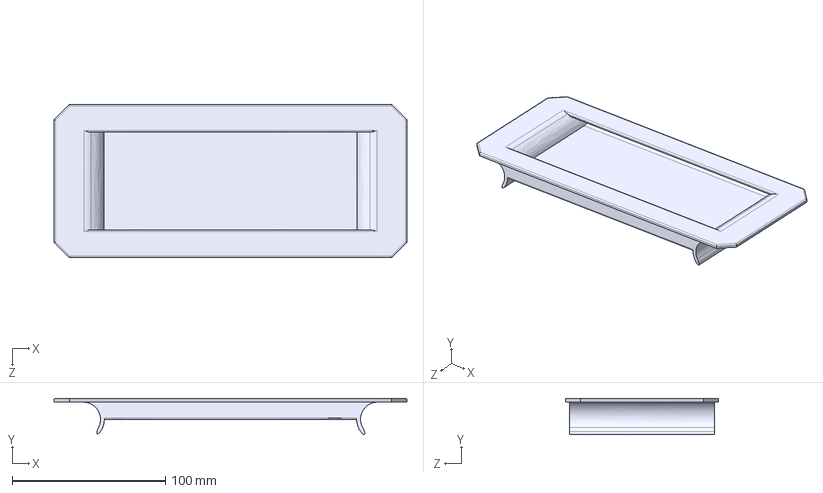
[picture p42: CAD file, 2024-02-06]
3D模型/2.0/储粮仓盖.STEP
230.1 x 23.6 x 100.0 mm

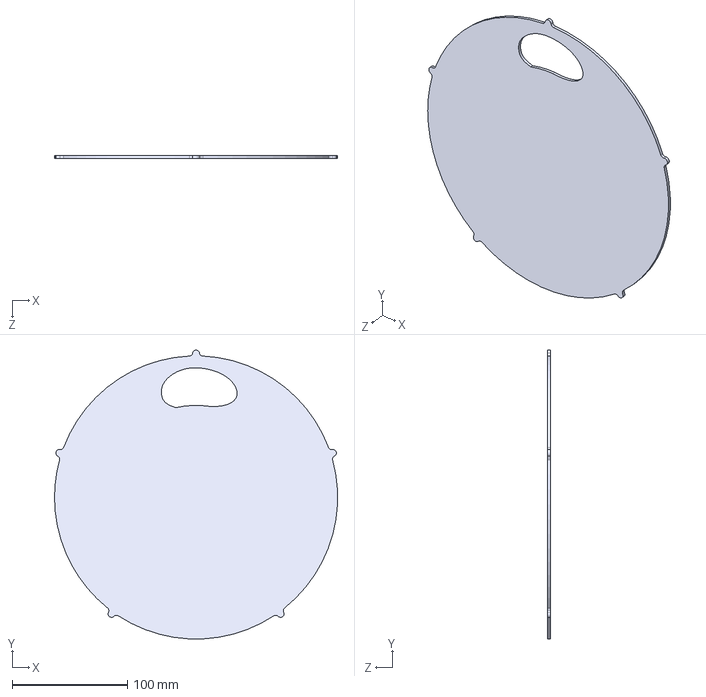
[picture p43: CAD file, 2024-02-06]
3D模型/2.0/全透挡板.STEP
245.8 x 250.8 x 2.50 mm

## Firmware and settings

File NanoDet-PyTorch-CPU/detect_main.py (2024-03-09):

import cv2, os, time, torch, argparse, datetime
from nanodet.util import cfg, load_config, Logger
from nanodet.model.arch import build_model
from nanodet.util import load_model_weight
from nanodet.data.transform import Pipeline
import OPi.GPIO as GPIO

from gpio_test import *


class Predictor(object):
    def __init__(self, cfg, model_path, logger, device='cpu'):
        self.cfg = cfg
        self.device = device
        model = build_model(cfg.model)
        ckpt = torch.load(model_path, map_location=lambda storage, loc: storage)
        load_model_weight(model, ckpt, logger)
        self.model = model.to(device).eval()
        self.pipeline = Pipeline(cfg.data.val.pipeline, cfg.data.val.keep_ratio)

    def inference(self, img):
        img_info = {}
        height, width = img.shape[:2]
        img_info['height'] = height
        img_info['width'] = width
        meta = dict(img_info=img_info,
                    raw_img=img,
                    img=img)
        meta = self.pipeline(meta, self.cfg.data.val.input_size)
        meta['img'] = torch.from_numpy(meta['img'].transpose(2, 0, 1)).unsqueeze(0).to(self.device)
        with torch.no_grad():
            results = self.model.inference(meta)
        return meta, results

    # 通过修改参数选择保存或者显示带标记框的输出图片
    def visualize(self, dets, meta, class_names, score_thres, save_path='', wait=0):
        time1 = time.time()
        self.model.head.show_result(meta['raw_img'], dets, class_names, score_thres=score_thres, show=False,
                                    save_path=save_path)
        print('viz time: {:.3f}s'.format(time.time() - time1))


# 调用摄像头拍一张照片
def take_photo():
    led('red',t1 = 0.2)

    cap = cv2.VideoCapture(1)
    cap.set(3,w)
    cap.set(4,h)
    ret, image = cap.read()
    print(f"分辨率: {cap.get(3)}x{cap.get(4)}")

    cap.release()
    if ret:
        return image
    else:
        raise ValueError('Could not take camera image')


food = 5
def power_电机(t1):
    global food
    # open
    GPIO.output(po_电机, 0)
    time.sleep(t1)

    # close
    GPIO.output(po_电机, 1)
    food = 5


def remain_food():
    global food
    GPIO.output(power_红外, 1)
    for i in range(10):
        time.sleep(0.1)
        if GPIO.input(pi_红外) == 1:
            print('remain')
            break
    else:
        print('not remain')
        GPIO.output(power_红外, 0)
        return False
    GPIO.output(power_红外, 0)
    return True


def find_something():
    GPIO.output(po_灯带, 0)
    GPIO.output(power_光敏电阻, 1)
    for i in range(20):
        time.sleep(0.1)
        if GPIO.input(pi_光敏电阻) == 1:
            print('?')
            break
    else:
        print('X')
        GPIO.output(power_光敏电阻, 0)
        GPIO.output(po_灯带, 1)
        return False
    GPIO.output(power_光敏电阻, 0)
    GPIO.output(po_灯带, 1)
    return True

led_trigger_mode = ['none', 'usb-gadget', 'usb-host', 'kbd-scrolllock', 'kbd-numlock', 'kbd-capslock', 'kbd-kanalock', 'kbd-shiftlock', 'kbd-altgrlock', 'kbd-ctrllock', 'kbd-altlock', 'kbd-shiftllock', 'kbd-shiftrlock', 'kbd-ctrlllock', 'kbd-ctrlrlock', 'usbport', 'disk-activity', 'disk-read', 'disk-write', 'ide-disk', 'mtd', 'nand-disk', 'heartbeat', 'cpu', 'cpu0', 'cpu1', 'cpu2', 'cpu3', 'activity', 'default-on', 'panic', 'mmc0', 'mmc2', 'mmc1', 'rfkill-any', 'rfkill-none', 'rfkill0', 'rc-feedback', 'rfkill1', 'bluetooth-power', 'hci0-power', 'rfkill2', 'stmmac-0:01:link', 'stmmac-0:01:1Gbps', 'stmmac-0:01:100Mbps', 'stmmac-0:01:10Mbps']
def led(color, mode='default-on', t1=0):
    if not t1:
        if mode in led_trigger_mode:
            os.system(f"sudo echo {mode} > /sys/devices/platform/leds/leds/{color}-led/trigger")
        else:
            print(f'{mode} is not supported led-mode')
    else:
        if mode in led_trigger_mode:
            os.system(f"sudo echo {mode} > /sys/devices/platform/leds/leds/{color}-led/trigger")
            time.sleep(t1)
            os.system(f"sudo echo none > /sys/devices/platform/leds/leds/{color}-led/trigger")
        else:
            print(f'{mode} is not supported led-mode')


def find_cat():
    # 开始推理时黄灯闪烁，发现猫黄灯常亮2-3s；未发现猫红灯常亮3s(所有推理结束后）
    led('green', 'heartbeat')
    raw_image = take_photo()

    # 整理由nanodet模型推理出的结果
    def sort_result(dets, score_thresh):
        for bbox in dets[15]:
            score = bbox[-1]
            if score > score_thresh:
                return True
        return False

    logger.log('开始推理')
    meta, res = predictor.inference(raw_image)
    if sort_result(res, 0.6):
        led('green')
        print('cat!cat!cat!')
        power_电机(2)
        predictor.visualize(res, meta, cfg.class_names, 0.6, save_path=f'{path_dir}/{i}_findcat.jpg')
        return True
    else:
        print('no cat')
        cv2.imwrite(f'{path_dir}/{i}.jpg', raw_image)
        return False


# -------------------------------------------------------------------------------------------------------------------

led('green')
led('red', mode='none')
# 加载推理模型
load_config(cfg, './config/nanodet-m.yml')
logger = Logger(-1, use_tensorboard=False)
predictor = Predictor(cfg, 'model/nanodet_m.pth', logger)

# 摄像头的分辨率宽高组合，根据摄像头需要调整
rank_ls = ((1024, 768), (1280, 720), (1600, 1200), (1920, 1080),
           (2048, 1536), (2592, 1944), (3264, 2448), (3840, 2160), (3840, 3104))
w, h = rank_ls[3]

while 1:  # 每隔10秒检测一次
    time.sleep(6)
    print(food)
    if find_something() and (not remain_food() or food == 0):

        dir = f'./capture/{datetime.datetime.now().strftime("%Y%m%d_%H%M%S")}'
        path_dir = dir + '/'
        os.makedirs(path_dir, exist_ok=True)

        for i in range(10):
            if find_cat():
                cap.release()
                os.renames(dir, dir + '_findcat')
                find = True

                # print('冷却600s...')
                led('green', '0')
                # time.sleep(600)
                led('green', '1')
                break
        else:
            cap.release()
            os.renames(dir, dir + '_no')
            # 红灯常亮3s
            led('red', t1=3)

            # print('冷却60s...')
            # led('green', '0')
            # time.sleep(60)
            # led('green', '1')
    else:
        time.sleep(3)

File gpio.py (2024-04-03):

import os, time
import OPi.GPIO as GPIO

'''
    开始检测前黄灯闪烁3s;
    正常运行时黄灯常亮，待机冷却状态只有充电宝亮灯；
    推理时黄灯闪烁，发现猫黄灯常亮2-3s；未发现猫红灯常亮3s(所有推理结束后）；
    出现错误红灯闪烁；
'''

# 引脚定义
power_光敏电阻 = 16;    pi_光敏电阻 = 18          # GND_光敏电阻 = 14
power_红外 = 5;        pi_红外 = 3              # GND_红外 = 6
po_电机 = 8          # power_电机 = 5v 2        # GND_电机 = 9
po_灯带 = 19         # power_灯带 = 5v 4        # GND_灯带 = 20


# GND = 6,9,14,20,25
# 5v = 2,4
# 3.3v = 1,17

# gpio初始化
GPIO.cleanup()
GPIO.setwarnings(False)
GPIO.setmode(GPIO.BOARD)

GPIO.setup(power_光敏电阻, GPIO.OUT);   GPIO.setup(pi_光敏电阻, GPIO.IN)
GPIO.setup(power_红外, GPIO.OUT);      GPIO.setup(pi_红外, GPIO.IN)
GPIO.setup(po_电机, GPIO.OUT)
GPIO.setup(po_灯带, GPIO.OUT)

# 初始化关闭
GPIO.output(po_电机, 1)
GPIO.output(po_灯带, 1)

def open_light(t1=2):
    GPIO.output(po_灯带, 0)
    time.sleep(t1)
    GPIO.output(po_灯带, 1)

def power_motor(t1=2):
    # 5r/min，30度/2s
    GPIO.output(po_电机, 0)
    time.sleep(t1)
    GPIO.output(po_电机, 1)

def remain_food():
    GPIO.output(power_红外, 1)
    for i in range(10):
        if GPIO.input(pi_红外) == 1:
            print('猫粮还有剩余')
            break
        time.sleep(0.1)
    else:
        print('猫粮所剩无几')
        GPIO.output(power_红外, 0)
        return False
    GPIO.output(power_红外, 0)
    return True

def find_something():
    GPIO.output(po_灯带, 0)
    GPIO.output(power_光敏电阻, 1)
    for i in range(20):
        if GPIO.input(pi_光敏电阻) == 1:
            print('光敏电阻有发现！')
            break
        time.sleep(0.1)
    else:
        print('X')
        GPIO.output(power_光敏电阻, 0)
        GPIO.output(po_灯带, 1)
        return False
    GPIO.output(power_光敏电阻, 0)
    GPIO.output(po_灯带, 1)
    return True

if __name__ == '__main__':
    while 1:
        if find_something() and remain_food():
            print('假装开始识别猫')
            time.sleep(5)
        else:
            print('没开始识别猫')

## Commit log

2024-02-06 first commit;
    [1.0组装示例.SLDASM, alexnet.param, blazeface.param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]
2024-02-06 add README；
2024-02-06 删除文件 NanoDet-PyTorch-CPU/.idea
2024-02-06 删除文件 gpio_test.py
2024-02-29 zipped models
    [1.0组装示例.SLDASM, 主仓.STEP, 储粮.STEP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]
2024-09-19 recovered the final
    [外壳.STEP]
